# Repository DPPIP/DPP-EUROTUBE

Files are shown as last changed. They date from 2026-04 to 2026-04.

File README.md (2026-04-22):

# DPP Hyperloop – Eurotube / FHNW

## Übersicht

Das System erstellt **Digitale Produktpässe (DPP)** für Beton-Fertigelemente eines Hyperloop-Prototyps. Es besteht aus vier Schichten:

```
┌─────────────────────────────────────────────────────────┐
│  Arduino (Sensoren + RFID + Servo)                      │
│  ↕ Seriell (USB, 9600 Baud, JSON)                       │
│  Python GUI (Tkinter) – Produktionssteuerung             │
│  ↕ Git Push / GitHub Pages                               │
│  Web-Viewer (viewer.html, batch/index.html)              │
│  ↕ ifcopenshell                                          │
│  IFC-Integration (Pset-Schreiber)                        │
└─────────────────────────────────────────────────────────┘
```

---

## Verzeichnisstruktur

```
DPP-EUROTUBE/
├── index.html                              ← Landing Page (GitHub Pages)
├── README.md
├── prototyp_final/
│   ├── hyperloop_dpp.py                    ← Haupt-Python-Skript (GUI + Logik)
│   ├── hyperloop_qr_prep.py               ← QR-Label-Generator (PDF)
│   ├── hyperloop_dpp_combined/
│   │   └── hyperloop_dpp_combined.ino     ← Arduino-Sketch (Final)
│   └── qr_labels/
│       ├── labels.pdf                      ← Druckbare QR-Etiketten (A4)
│       └── prepared.json                   ← Manifest der generierten SNs
├── hardware/
│   ├── 3d_print/                           ← STL-Dateien (Schalung + Tisch)
│   │   ├── EuroTube_Mold_Left.stl / _V2.stl
│   │   ├── EuroTube_Mold_Right.stl / _V2.stl
│   │   ├── EuroTube_Table.stl / _V2.stl
│   │   └── EuroTube_Tubesegment.stl
│   └── arduino/
│       ├── sketch.ino                      ← Arduino-Sketch (Wokwi)
│       ├── diagram.json                    ← Elektronisches Schema (Wokwi)
│       ├── libraries.txt                   ← Bibliotheksliste
│       ├── wokwi-project.txt               ← Wokwi-Projekt-Link
│       └── komponenten.md                  ← Komponentenliste
├── passports/
│   ├── viewer.html                         ← Einzel-DPP Viewer (Web)
│   └── *.jsonld                            ← Generierte Segment-Passports
├── batch/
│   ├── index.html                          ← Batch-Viewer + Scanner (Web)
│   └── *.jsonld                            ← Generierte Batch-Passports
├── IFC/
│   ├── IP3.ifc                             ← Quell-IFC-Modell
│   ├── add_dpp_links.py                    ← V1: DPP-URLs ins IFC
│   ├── add_dpp_data.py                     ← V2: Alle DPP-Daten ins IFC
│   ├── IP3_DPP_Batchlinks.ifc             ← Output V1
│   └── IP3_DPP_abgefüllt.ifc             ← Output V2
├── Handlungsempfehlungen/
│   ├── handlungsempfehlungen.html          ← Viewer (GitHub Pages)
│   └── Handlungsempfehlungen_DPP.pdf      ← PDF
└── .gitignore
```

---

## 1. Hardware

### Komponenten

| Kategorie | Komponente |
|---|---|
| Mikrocontroller | Arduino Uno |
| Module und Sensoren | RFID-Modul RC522 |
| | DHT22 / DHT11 |
| Eingabe und Ausgabe | 2 Servomotoren |
| | Drucktaster |
| Verkabelung und Prototyping | Steckbrett, Widerstand, Jumperkabel |
| Stromversorgung | Batteriepack (4 × 1.5 V) |

### Elektronisches Schema

Das Schaltschema ist als Wokwi-Simulation verfügbar:  
`hardware/arduino/diagram.json` – importierbar unter https://wokwi.com/projects/461746891808954369

### 3D-Druckteile

Die physische Schalung (SMF) wurde als Prototyp gedruckt. Die STL-Dateien liegen unter `hardware/3d_print/`:

| Datei | Beschreibung |
|---|---|
| `EuroTube_Mold_Left.stl` / `_V2.stl` | Linke Schalungshälfte |
| `EuroTube_Mold_Right.stl` / `_V2.stl` | Rechte Schalungshälfte |
| `EuroTube_Table.stl` / `_V2.stl` | Produktionstisch |
| `EuroTube_Tubesegment.stl` | Röhrensegment-Modell |

---

## 2. Arduino – `hyperloop_dpp_combined.ino`

### Zweck
Steuert die physische Hardware: DHT11-Sensor (Temperatur/Feuchtigkeit), Servo (Schalung öffnen/schliessen), MFRC522 (RFID/NFC-Leser).

### Pin-Belegung

| Komponente | Pin |
|---|---|
| DHT11 | 2 |
| Taster | 3 (INPUT_PULLUP) |
| Servo | 6 |
| RFID RST | 9 |
| RFID SS | 10 |
| SPI | 11, 12, 13 (Standard) |

### Serielles Protokoll (JSON, 9600 Baud)

**Eingabe (Python → Arduino):**
- `C` – Schalung schliessen, Messung starten
- `O` – Schalung öffnen, Messung stoppen

**Ausgabe (Arduino → Python):**
```json
{"type":"boot","msg":"System bereit (DHT+Servo+RFID)"}
{"type":"event","event":"cmd_start"}
{"type":"sensor","grund":"periodic","temp":22.5,"hum":58.0,"servo":5}
{"type":"event","event":"cmd_stopp"}
{"type":"rfid","url":"https://w3id.org/hyperloop-dpp/01/09999000000001/21/1234567890"}
{"type":"rfid_error","msg":"Auth fehlgeschlagen"}
```

### RFID-Lesevorgang
- Liest NDEF-URL-Records von MIFARE Classic 1K Karten
- Sektor 1 (Blöcke 4–6) + Sektor 2 (Blöcke 8–10) = 96 Bytes
- Authentifizierung mit NFC-Forum-Key: `D3 F7 D3 F7 D3 F7`
- NDEF-Prefix `0x04` = `https://`, Terminator `0xFE` = Ende
- Nach erfolgreichem Scan wird `rfidAktiv = false` gesetzt (einmaliger Scan pro Zyklus)

### Ablauf
1. Taster oder `C`-Befehl → Schalung schliesst, Sensoraufzeichnung startet
2. Alle 2 Sekunden wird `{"type":"sensor",...}` gesendet
3. Taster oder `O`-Befehl → Schalung öffnet, RFID-Scan wird aktiviert
4. RFID-Karte erkannt → URL wird gesendet, Scan deaktiviert

---

## 3. Python GUI – `hyperloop_dpp.py`

### Zweck
Desktop-Anwendung (Tkinter) zur Produktionssteuerung. Empfängt Sensordaten vom Arduino, erstellt JSON-LD Passports und pusht sie via Git auf GitHub Pages.

### Abhängigkeiten
```
pip install pyserial qrcode[pil]
```
Optional (für Kamera-QR-Scan): `pip install opencv-python pyzbar`

### Konfiguration (Konstanten im Skript)

| Konstante | Wert | Beschreibung |
|---|---|---|
| `PORT` | `COM7` | Serieller Port des Arduino |
| `BAUD` | `9600` | Baudrate |
| `W3ID_BASE` | `https://w3id.org/hyperloop-dpp` | Basis-URI für GS1 Digital Links |
| `GTIN` | `09999000000001` | GS1 GTIN-14 des Produkts |
| `GITHUB_PAGES` | `https://DPPIP.github.io/DPP-EUROTUBE` | GitHub Pages URL |
| `GITHUB_REPO` | `C:/Users/david/Documents/DPP-EUROTUBE` | Lokaler Pfad zum Git-Repo |
| `BSDD_BASE` | `.../HYPER-DPP/0.6` | bSDD Datenkatalog Version |
| `BETONSORTE` | `C25/30` | Standardwert (überschreibbar in GUI) |
| `HERSTELLUNGSORT` | `Koblenz` | Standardwert (überschreibbar in GUI) |

### Hauptfunktionen

#### `extrahiere_id(scanned: str) -> str`
Extrahiert die Seriennummer aus einem GS1 Digital Link URI:
- `https://w3id.org/.../21/1234567890` → `1234567890`
- `https://w3id.org/.../10/4521` → `4521`
- `1234567890` → `1234567890`

#### `erstelle_jsonld(eintrag: dict) -> dict`
Generiert das JSON-LD Dokument für ein Segment. Verwendet bSDD 0.6 Property-Namen:

| JSON-LD Key | Inhalt |
|---|---|
| `bsdd:SegmentID` | Seriennummer |
| `bsdd:StrengthClass` | Betonsorte (aus GUI-Eingabe) |
| `bsdd:AssemblyPlace` | Herstellungsort (aus GUI-Eingabe) |
| `bsdd:ManufactoringDate` | ISO-Zeitstempel |
| `bsdd:ReferenceEnvironmentTemperature` | Durchschnittstemperatur in °C |
| `bsdd:ReferenceAirRelativeHumidity` | Durchschnittliche Luftfeuchtigkeit in % |
| `bsdd:Schalungsdauer` | Dauer in Stunden (Minuten / 60) |
| `bsdd:Status` | `Aktiv` |

#### `github_push(serial_nr: str, dateien: list)`
1. `git pull --rebase --autostash` (verhindert Konflikte)
2. Dateien ins Repo kopieren
3. `git add`, `git commit`, `git push`

#### `speichere_und_publiziere(t_med, h_med, dauer, segment_id)`
Erstellt JSON-LD, speichert lokal unter `passports/{sn}.jsonld`, pusht via Git.

#### `zeige_scan_dialog(t_med, h_med, dauer)`
Nach Produktionsstopp öffnet sich ein Dialog mit:
- **Kamera-Preview** (OpenCV + pyzbar) – erkennt QR-Codes automatisch
- **RFID-Callback** – Arduino sendet URL, Dialog reagiert automatisch
- **Manuelles Eingabefeld** – Fallback für USB-Scanner
- **Duplikatprüfung** – HEAD-Request auf GitHub Pages, verhindert doppelte Vergabe

#### `lese_seriell()`
Polling-Funktion (alle 100 ms via `root.after`). Verarbeitet JSON-Nachrichten vom Arduino:
- `cmd_start`/`system_start` → Aufzeichnung starten, Sensor-Arrays leeren
- `sensor` → Temperatur/Feuchtigkeit sammeln
- `rfid` → ID extrahieren, an Scan-Dialog weiterleiten
- `cmd_stopp`/`system_stopp` → Median berechnen, Scan-Dialog öffnen

### GUI-Elemente
- **Statusanzeige**: Schalung offen/geschlossen, aktueller Zustand
- **Eingabefelder**: Betonsorte und Herstellungsort (editierbar, Standardwerte)
- **Buttons**: "Schliessen & Start" / "Öffnen & Stopp"
- **DPP-Liste**: Scrollbare Liste aller erstellten Passports (Doppelklick öffnet im Browser)
- **URI-Label**: Klickbar, öffnet den zuletzt erstellten DPP im Browser

---

## 4. QR-Label-Generator – `hyperloop_qr_prep.py`

### Zweck
Generiert druckbare QR-Code-Etiketten als A4-PDF. Jedes Label enthält eine eindeutige GS1 Digital Link URI.

### Abhängigkeiten
```
pip install qrcode[pil] reportlab
```

### Konfiguration

| Konstante | Wert |
|---|---|
| `COUNT` | 11 (eindeutige SNs) |
| `COLS × ROWS` | 3 × 8 = 24 Plätze |
| Labels total | 13 (11 einmalig + 2 Duplikate) |

### Output
- `qr_labels/labels.pdf` – A4, randlos, QR 90° gedreht
- `qr_labels/prepared.json` – Manifest `[{id, uri, used}, ...]`

### Label-Aufbau
```
┌──────────────────────────────────┐
│ [QR 90°]  Digital Product Passport│
│           https://w3id.org/.../   │
│           01/GTIN/21/             │
│           1234567890  (fett)      │
└──────────────────────────────────┘
```

### Seriennummern
10-stellig, zufällig generiert (`random.randint(1000000000, 9999999999)`). Die ersten zwei SNs werden doppelt gedruckt (für Duplikat-Tests).

---

## 5. Web-Viewer – `passports/viewer.html`

### Zweck
Rendert ein einzelnes Segment-DPP im Browser. Wird auf GitHub Pages gehostet, Daten werden per Fetch aus den `.jsonld`-Dateien geladen.

### URL-Parameter
- `?sn=1234567890` – Seriennummer des Segments (Pflicht)
- `?single=1` – Batch-Redirect unterdrücken

### Ablauf
1. `sn` aus URL lesen
2. Fetch `passports/{sn}.jsonld` von GitHub Pages
3. Wenn `@type` = `HyperloopBatch` → Redirect zu `batch/index.html`
4. Wenn `bsdd:BatchID` vorhanden und kein `?single=1` → Redirect zum Batch
5. Render: 7 Felder (Betonsorte, Herstellungsort, Datum, Temperatur, Schalungsdauer, Status, Luftfeuchtigkeit)
6. QR-Code generieren (qrcodejs)

### Angezeigte Felder
| Feld | JSON-LD Key |
|---|---|
| Betonsorte | `bsdd:StrengthClass` |
| Herstellungsort | `bsdd:AssemblyPlace` |
| Herstellungsdatum | `bsdd:ManufactoringDate.@value` |
| Herstellungstemperatur | `bsdd:ReferenceEnvironmentTemperature.@value` |
| Dauer in der Schalung | `bsdd:Schalungsdauer.@value` |
| Status | `bsdd:Status` |
| Luftfeuchtigkeit | `bsdd:ReferenceAirRelativeHumidity.@value` |

---

## 6. Batch-Viewer – `batch/index.html`

### Zweck
Zwei Modi in einer Datei:
1. **Scanner-Modus** (`index.html` ohne Parameter): QR-Scanner zum Erstellen neuer Batches
2. **Batch-Ansicht** (`?batch=ID`): Anzeige eines bestehenden Batches

### Scanner-Modus
- Kamera-basierter QR-Scanner (html5-qrcode)
- 5 Segmente scannen → "Batch erstellen"
- Erstellt `batch/{batchId}.jsonld` via GitHub API (Token im localStorage)
- Schreibt `bsdd:BatchID` in jedes Segment-JSONLD zurück
- Duplikatschutz: Segment mit existierender BatchID wird abgelehnt

### Batch-Ansicht
- Titel: "Batch Röhrensegment 10 M"
- Batch-Karte: Batch-ID, Verbindungsdatum
- Bestandteile: Pro Segment → Bauteiltyp, Betonsorte, Herstellungsort, Temperatur, Schalungsdauer
- Status-Karte: Verbunden/offen, Einbaudatum
- Buttons: Link kopieren, JSON-LD anzeigen

### Batch JSON-LD Struktur
```json
{
  "@type": ["dpp:DigitalProductPassport", ".../HyperloopBatch"],
  "bsdd:Batch_ID": "4873316459",
  "bsdd:Verbindungsdatum": {"@value": "2026-04-15T10:35:24"},
  "bsdd:VerlinkungBauteile": ["https://w3id.org/.../21/SN1", "..."],
  "bsdd:Status": "Verbunden",
  "bsdd:Material": "SikaProof",
  "bsdd:Spannstahlsorte": "St1570",
  "bsdd:Klebertyp": "PCI"
}
```

---

## 7. IFC-Integration – `add_dpp_links.py` / `add_dpp_data.py`

### Zweck
Schreibt DPP-Informationen in ein bestehendes IFC-Modell (IP3.ifc) via ifcopenshell.

### Abhängigkeiten
```
pip install ifcopenshell
```

### IFC-Struktur

```
IfcElementAssembly  "Batch"       (Röhrensegment 10m = 5 Betonelemente)
  ├── IfcBuildingElementProxy  "Betonsegment_2m10"
  ├── IfcBuildingElementProxy  "Betonsegment_2m11"
  ├── IfcBuildingElementProxy  "Betonsegment_2m12"
  ├── IfcBuildingElementProxy  "Betonsegment_2m13"
  ├── IfcBuildingElementProxy  "Betonsegment_2m14"
  ├── IfcCovering              "Beschichtung"
  ├── IfcReinforcingBar        "Spannstahl" (×5)
  └── IfcFastener              "Kleber" (×4)
```

### Variante 1 – `add_dpp_links.py` → `IP3_DPP_v1.ifc`
Schreibt nur DPP-URLs in ein einziges Pset:

| Element | Pset | Property | Wert |
|---|---|---|---|
| IfcElementAssembly | `ePset_DigitalProductPassport` | `URL` | Batch-Viewer-Link |
| IfcBuildingElementProxy | `ePset_DigitalProductPassport` | `URL` | GS1 Digital Link URI |

### Variante 2 – `add_dpp_data.py` → `IP3_DPP_v2.ifc`
Schreibt alle DPP-Daten gemäss IFC-Mapping in mehrere Psets:

**IfcElementAssembly (Batch):**

| Pset | Properties |
|---|---|
| `ePset_DigitalProductPassport` | URL, Batch_ID, Verbindungsdatum, Status, Einbaudatum |

**IfcBuildingElementProxy (Segment):**

| Pset | Properties |
|---|---|
| `ePset_DigitalProductPassport` | URL |
| `Pset_ConcreteElementGeneral` | StrengthClass |
| `Pset_ManufacturerTypeInformation` | AssemblyPlace |
| `Pset_ManufacturerOccurrence` | ManufactoringDate |
| `Pset_EnvironmentalCondition` | ReferenceEnvironmentTemperature, ReferenceAtRelativeHumidity |
| `Pset_Herstellung` | Schalungsdauer, Status |

---

## URI-Schema (GS1 Digital Link)

```
https://w3id.org/hyperloop-dpp/01/{GTIN}/21/{Serial}   → Segment
https://w3id.org/hyperloop-dpp/01/{GTIN}/10/{BatchID}   → Batch
```

- **AI 01** = GTIN-14 (`09999000000001`)
- **AI 21** = Seriennummer (SGTIN, Segment-Ebene)
- **AI 10** = Losnummer (LGTIN, Batch-Ebene)
- W3ID leitet via `.htaccess` auf GitHub Pages weiter (PR pending bei perma-id/w3id.org)

---

## Datenfluss

```
1. Schalung schliessen (Button/Taster)
   → Arduino: Servo schliesst, Sensormessung startet

2. Sensordaten sammeln (alle 2s)
   → Arduino sendet JSON → Python sammelt Temperatur + Feuchtigkeit

3. Schalung öffnen (Button/Taster)
   → Arduino: Servo öffnet, RFID-Scan aktiviert
   → Python: Median berechnen, Scan-Dialog öffnen

4. QR-Code / RFID scannen
   → Kamera, RFID oder manuell → Segment-ID extrahiert
   → Duplikatprüfung (HEAD-Request auf GitHub Pages)

5. DPP erstellen und publizieren
   → JSON-LD generieren → lokal speichern
   → git pull --rebase → git add → git commit → git push
   → GitHub Pages aktualisiert automatisch

6. Batch erstellen (batch/index.html)
   → 5 Segmente scannen → Batch-JSONLD via GitHub API erstellen
   → BatchID in jedes Segment-JSONLD zurückschreiben

7. IFC-Integration (optional)
   → add_dpp_links.py oder add_dpp_data.py
   → Schreibt URLs / Daten in IFC-Psets
```

---

## Bekannte Limitierungen

- **Fehlerbehandlung**: `except Exception: pass` in der seriellen Leseroutine schluckt Fehler still. Bei Produktionseinsatz sollte Logging ergänzt werden.
- **Blockierender HTTP-Call**: Die Duplikatprüfung (`urllib.request.urlopen`) blockiert kurzzeitig die GUI. Bei schlechtem Netzwerk kann dies zu Verzögerungen führen.
- **Git-Push**: Verwendet `subprocess` für Git-Befehle. Bei Merge-Konflikten kann der Push fehlschlagen (wird in Konsole ausgegeben).
- **Kamera-Freigabe**: Bei unerwartetem Schliessen des Scan-Dialogs kann die Kamera-Ressource blockiert bleiben.
- **Prototyp-Charakter**: Das Skript ist für den Laborbetrieb an der FHNW konzipiert, nicht für industriellen Einsatz.

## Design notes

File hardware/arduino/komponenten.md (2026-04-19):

# Arduino Komponenten – Hyperloop DPP Prototyp

| Kategorie | Komponente |
|---|---|
| Mikrocontroller | Arduino Uno |
| Module und Sensoren | RFID-Modul RC522 |
| | DHT22 / DHT11 |
| Eingabe und Ausgabe | 2 Servomotoren |
| | Drucktaster |
| Verkabelung und Prototyping | Steckbrett |
| | Kleines Steckbrett |
| | Widerstand |
| | Jumperkabel |
| Stromversorgung | Batteriepack (4 × 1.5 V) |

## Simulation

Das Schaltschema wurde mit [Wokwi](https://wokwi.com/projects/461746891808954369) erstellt und simuliert.  
Die Dateien `sketch.ino` und `diagram.json` in diesem Ordner können direkt in Wokwi importiert werden.

## Pin-Belegung

| Komponente | Pin |
|---|---|
| DHT11/22 | 2 |
| Drucktaster | 3 (INPUT_PULLUP) |
| Servo | 6 |
| RFID RST | 9 |
| RFID SS (SDA) | 10 |
| RFID MOSI | 11 |
| RFID MISO | 12 |
| RFID SCK | 13 |

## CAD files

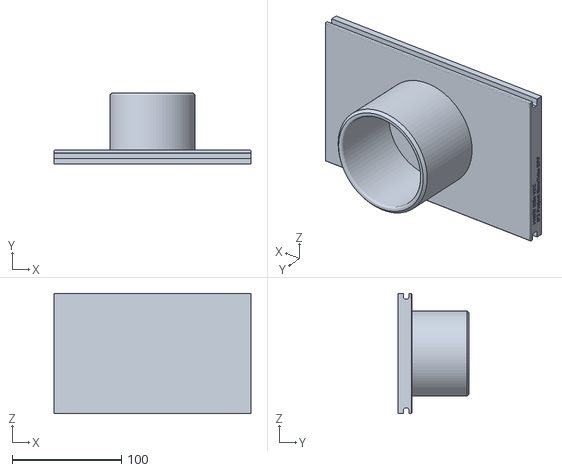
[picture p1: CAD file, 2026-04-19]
hardware/3d_print/EuroTube__Table_V2.stl
180.0 x 65.0 x 110.0

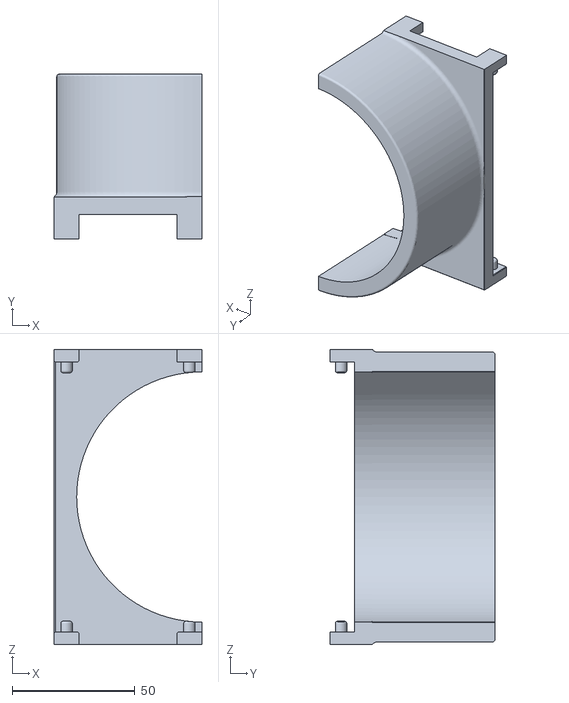
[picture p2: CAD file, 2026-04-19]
hardware/3d_print/EuroTube_Mold_Left.stl
60.0 x 67.0 x 120.0

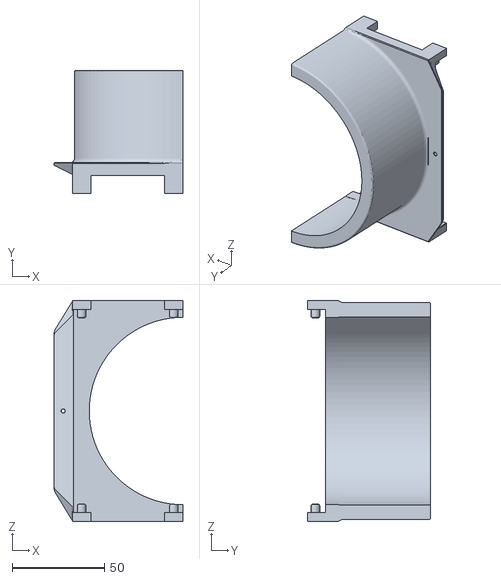
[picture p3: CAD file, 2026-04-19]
hardware/3d_print/EuroTube_Mold_Left_V2.stl
70.0 x 67.0 x 120.0

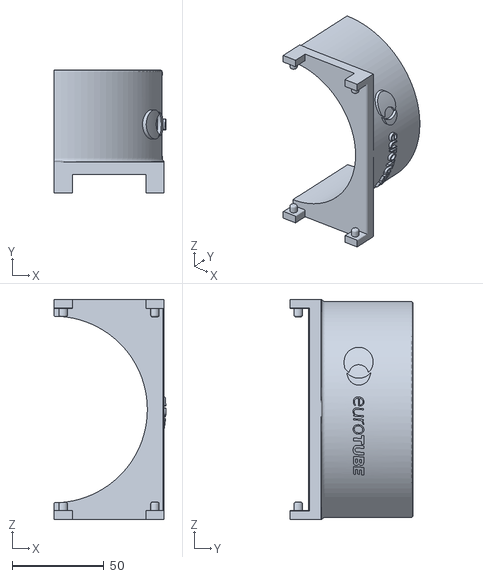
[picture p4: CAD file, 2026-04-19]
hardware/3d_print/EuroTube_Mold_Right.stl
61.0 x 67.0 x 120.0

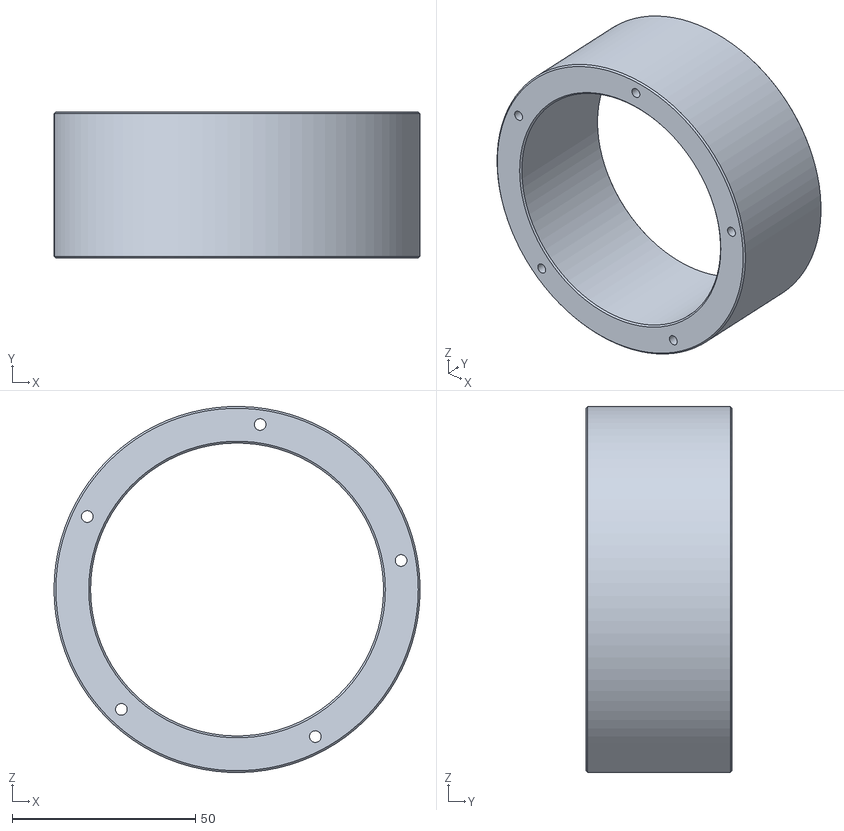
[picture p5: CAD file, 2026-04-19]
hardware/3d_print/EuroTube_Tubesegment.stl
100.0 x 40.0 x 100.0

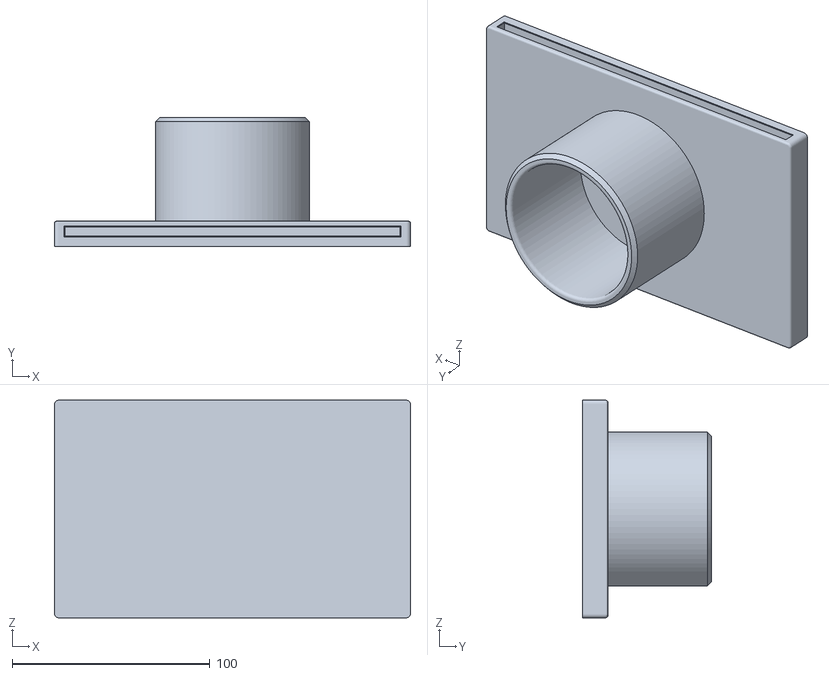
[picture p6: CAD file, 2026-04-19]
hardware/3d_print/EuroTube_Table.stl
180.0 x 65.0 x 110.0

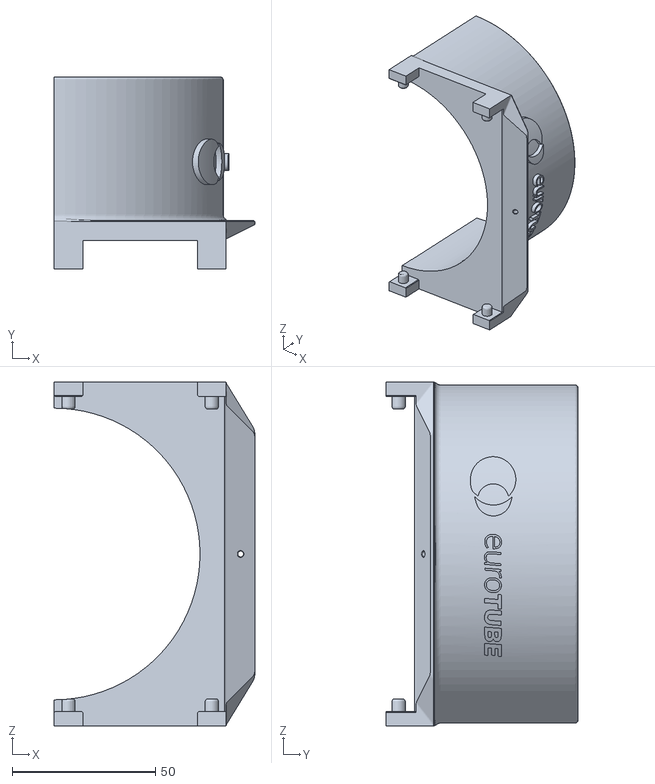
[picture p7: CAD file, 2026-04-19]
hardware/3d_print/EuroTube__Mold_Right_V2.stl
70.0 x 67.0 x 120.0

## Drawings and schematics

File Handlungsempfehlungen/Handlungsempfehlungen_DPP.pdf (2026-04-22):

## Digital Twin verbessern

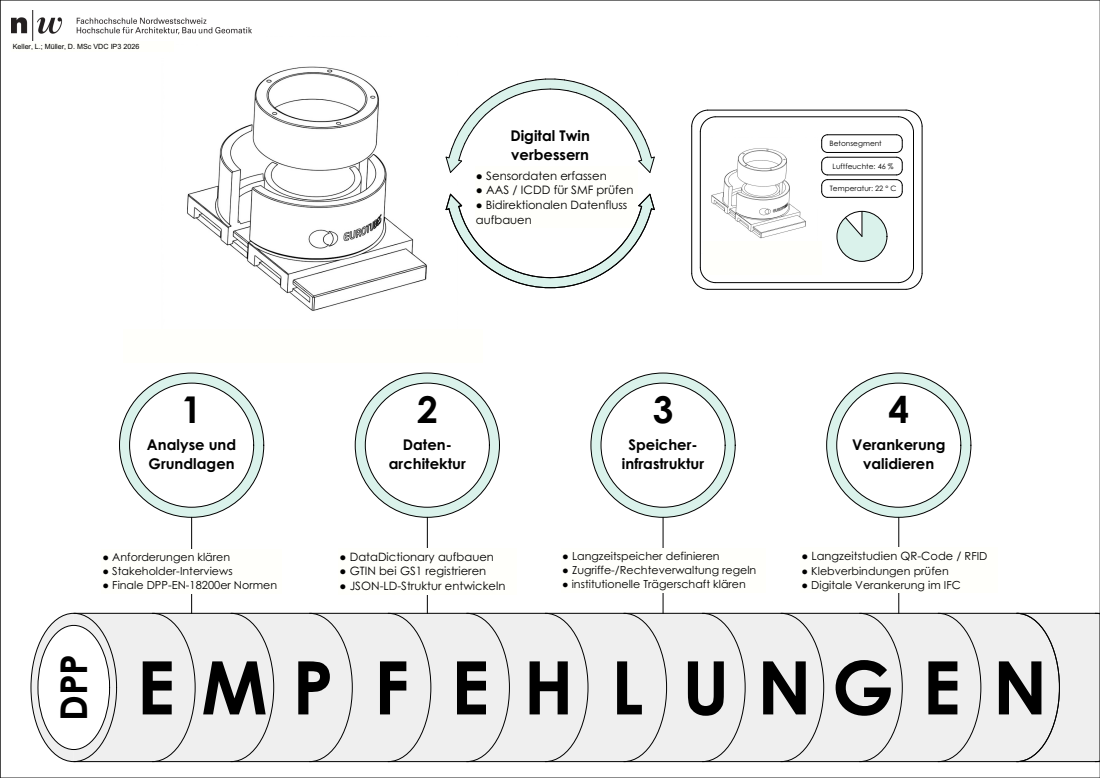
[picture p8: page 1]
GSEducationalVersion; Analyse und Grundlagen; Daten- architektur; Speicher- infrastruktur; Verankerung validieren; DPP; Betonsegment; Luftfeuchte: 46 %; Temperatur: 22 ° C

Keller, L.; Müller, D. MSc VDC IP3 2026

● Sensordaten erfassen
● AAS / ICDD für SMF prüfen
● Bidirektionalen Datenfluss
aufbauen

● Anforderungen klären
● Stakeholder-Interviews
● Finale DPP-EN-18200er Normen

● DataDictionary aufbauen
● GTIN bei GS1 registrieren
● JSON-LD-Struktur entwickeln

● Langzeitspeicher definieren
● Zugriffe-/Rechteverwaltung regeln
● institutionelle Trägerschaft klären

● Langzeitstudien QR-Code / RFID
● Klebverbindungen prüfen
● Digitale Verankerung im IFC

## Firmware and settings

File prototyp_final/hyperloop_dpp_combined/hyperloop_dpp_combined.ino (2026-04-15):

/**
 * hyperloop_dpp_combined.ino
 * ──────────────────────────
 * Kombiniert: DHT11-Sensor + Servo (Schalung) + RFID-Leser (MFRC522)
 *
 * Pins:
 *   DHT11   → Pin 2
 *   Taster  → Pin 3
 *   Servo   → Pin 6
 *   RFID RST→ Pin 9
 *   RFID SS → Pin 10
 *   RFID SPI→ 11 (MOSI), 12 (MISO), 13 (SCK) [Standard Arduino SPI]
 *
 * Bibliotheken:
 *   DHT sensor library (Adafruit)
 *   Servo (built-in)
 *   MFRC522 (Miguel Balboa)
 *
 * Protokoll (seriell, 9600 Baud):
 *   Befehle von Python: 'C' = schliessen/start, 'O' = öffnen/stopp
 *   Ausgaben JSON:
 *     {"type":"boot","msg":"System bereit"}
 *     {"type":"event","event":"cmd_start"}
 *     {"type":"sensor","grund":"periodic","temp":22.5,"hum":58.0,"servo":5}
 *     {"type":"event","event":"cmd_stopp"}
 *     {"type":"rfid","url":"https://w3id.org/hyperloop-dpp/SN-..."}
 *     {"type":"rfid_error","msg":"Karte nicht lesbar"}
 */

#include "DHT.h"
#include <Servo.h>
#include <SPI.h>
#include <MFRC522.h>

// ─── Pins ────────────────────────────────────────────────────────────────────
#define DHTPIN       2
#define DHTTYPE      DHT11
#define TASTER_PIN   3
#define SERVO_PIN    6
#define RST_PIN      9
#define SS_PIN       10

// ─── Intervalle ──────────────────────────────────────────────────────────────
#define SENSOR_INTERVALL 2000

// ─── Objekte ─────────────────────────────────────────────────────────────────
DHT      dht(DHTPIN, DHTTYPE);
Servo    schalung;
MFRC522  mfrc522(SS_PIN, RST_PIN);
MFRC522::MIFARE_Key rfidKey;

// ─── Zustandsvariablen ───────────────────────────────────────────────────────
bool sensorAktiv          = false;
bool rfidAktiv            = false;   // true = Scan wird erwartet (Schalung offen)
bool letzterTasterZustand = HIGH;
unsigned long letzterSensorSend = 0;
int aktuellerWinkel       = 85;


// ─── Hilfsfunktionen ─────────────────────────────────────────────────────────

void sendeStatus(const char* grund) {
  float temp = dht.readTemperature();
  float hum  = dht.readHumidity();

  Serial.print("{\"type\":\"sensor\",\"grund\":\"");
  Serial.print(grund);
  Serial.print("\",\"temp\":");
  if (!isnan(temp)) Serial.print(temp, 1); else Serial.print("\"null\"");
  Serial.print(",\"hum\":");
  if (!isnan(hum))  Serial.print(hum, 1);  else Serial.print("\"null\"");
  Serial.print(",\"servo\":");
  Serial.print(aktuellerWinkel);
  Serial.println("}");
}

void oeffneSchalung() {
  schalung.attach(SERVO_PIN);
  aktuellerWinkel = 85;
  schalung.write(aktuellerWinkel);
  delay(400);
  schalung.detach();
}

void schliesseSchalung() {
  schalung.attach(SERVO_PIN);
  aktuellerWinkel = 5;
  schalung.write(aktuellerWinkel);
  delay(400);
  schalung.detach();
}

// ─── RFID lesen ──────────────────────────────────────────────────────────────

void leseRFID() {
  if (!mfrc522.PICC_IsNewCardPresent() || !mfrc522.PICC_ReadCardSerial()) return;

  MFRC522::StatusCode status;
  byte buffer[18];
  byte size = sizeof(buffer);
  String fullData = "";

  // Authentifizierung Sektor 1 (Block 4) und lese Blöcke 4–6
  status = mfrc522.PCD_Authenticate(
    MFRC522::PICC_CMD_MF_AUTH_KEY_A, 4, &rfidKey, &(mfrc522.uid)
  );
  if (status != MFRC522::STATUS_OK) {
    Serial.println("{\"type\":\"rfid_error\",\"msg\":\"Auth fehlgeschlagen\"}");
    mfrc522.PICC_HaltA();
    return;
  }
  for (byte block = 4; block <= 6; block++) {
    status = mfrc522.MIFARE_Read(block, buffer, &size);
    if (status == MFRC522::STATUS_OK) {
      for (byte i = 0; i < 16; i++) fullData += (char)buffer[i];
    }
  }

  // Authentifizierung Sektor 2 (Block 8) und lese Blöcke 8–10
  status = mfrc522.PCD_Authenticate(
    MFRC522::PICC_CMD_MF_AUTH_KEY_A, 8, &rfidKey, &(mfrc522.uid)
  );
  if (status == MFRC522::STATUS_OK) {
    for (byte block = 8; block <= 10; block++) {
      status = mfrc522.MIFARE_Read(block, buffer, &size);
      if (status == MFRC522::STATUS_OK) {
        for (byte i = 0; i < 16; i++) fullData += (char)buffer[i];
      }
    }
  }

  mfrc522.PICC_HaltA();
  mfrc522.PCD_StopCrypto1();

  // URL aus NDEF-Daten extrahieren
  String url = "";
  int headerIndex = -1;

  for (int i = 0; i < (int)fullData.length(); i++) {
    if (fullData[i] == 0x55) { headerIndex = i; break; }
  }

  if (headerIndex != -1 && headerIndex + 1 < (int)fullData.length()) {
    byte prefix = fullData[headerIndex + 1];
    if      (prefix == 0x01) url = "http://www.";
    else if (prefix == 0x02) url = "https://www.";
    else if (prefix == 0x03) url = "http://";
    else if (prefix == 0x04) url = "https://";

    for (int i = headerIndex + 2; i < (int)fullData.length(); i++) {
      byte c = fullData[i];
      if (c == 0xFE) break;
      if (c >= 32 && c <= 126) url += (char)c;
    }
  }

  if (url.length() > 0) {
    Serial.print("{\"type\":\"rfid\",\"url\":\"");
    Serial.print(url);
    Serial.println("\"}");
    rfidAktiv = false;  // Einmalig – nach erfolgtem Scan zurücksetzen
  } else {
    Serial.println("{\"type\":\"rfid_error\",\"msg\":\"Keine URL auf Karte\"}");
  }
}


// ─── Setup ───────────────────────────────────────────────────────────────────

void setup() {
  Serial.begin(9600);
  dht.begin();
  pinMode(TASTER_PIN, INPUT_PULLUP);

  // Servo Startposition
  schalung.attach(SERVO_PIN);
  schalung.write(aktuellerWinkel);
  delay(400);
  schalung.detach();

  // SPI + RFID initialisieren
  SPI.begin();
  mfrc522.PCD_Init();

  // NFC-Forum Key (D3 F7 D3 F7 D3 F7)
  for (byte i = 0; i < 6; i++) {
    rfidKey.keyByte[i] = (i % 2 == 0) ? 0xD3 : 0xF7;
  }

  Serial.println("{\"type\":\"boot\",\"msg\":\"System bereit (DHT+Servo+RFID)\"}");
}


// ─── Loop ────────────────────────────────────────────────────────────────────

void loop() {

  // ── 1. Befehle von Python lesen ──────────────────────────────────────────
  if (Serial.available() > 0) {
    char cmd = Serial.read();

    if (cmd == 'C') {
      sensorAktiv = true;
      rfidAktiv   = false;   // kein Scan während Messung
      schliesseSchalung();
      Serial.println("{\"type\":\"event\",\"event\":\"cmd_start\"}");
      sendeStatus("start");
      letzterSensorSend = millis();
    }
    else if (cmd == 'O') {
      sensorAktiv = false;
      rfidAktiv   = true;    // Scan wird jetzt erwartet
      oeffneSchalung();
      Serial.println("{\"type\":\"event\",\"event\":\"cmd_stopp\"}");
    }
  }

  // ── 2. Taster abfragen ───────────────────────────────────────────────────
  bool aktuellerTasterZustand = digitalRead(TASTER_PIN);

  if (aktuellerTasterZustand == LOW && letzterTasterZustand == HIGH) {
    sensorAktiv = !sensorAktiv;
    schalung.attach(SERVO_PIN);

    if (sensorAktiv) {
      rfidAktiv = false;
      schliesseSchalung();
      Serial.println("{\"type\":\"event\",\"event\":\"system_start\"}");
      sendeStatus("start");
      letzterSensorSend = millis();
    } else {
      rfidAktiv = true;      // Scan erwartet nach manuellem Öffnen
      oeffneSchalung();
      Serial.println("{\"type\":\"event\",\"event\":\"system_stopp\"}");
    }
    delay(50);
  }

  letzterTasterZustand = aktuellerTasterZustand;

  // ── 3. Sensordaten senden ────────────────────────────────────────────────
  if (sensorAktiv) {
    unsigned long jetzt = millis();
    if (jetzt - letzterSensorSend >= SENSOR_INTERVALL) {
      letzterSensorSend = jetzt;
      sendeStatus("periodic");
    }
  }

  // ── 4. RFID prüfen (nur wenn Scan erwartet wird) ─────────────────────────
  if (rfidAktiv) {
    leseRFID();
  }
}

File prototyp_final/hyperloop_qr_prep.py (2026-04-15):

"""
hyperloop_qr_prep.py – QR-Code Vorbereitung
============================================
Erstellt vorgedruckte QR-Code Labels mit W3ID URIs.

Output:
  qr_labels/labels.pdf   – druckbares A4-PDF, 3 Spalten × 8 Zeilen, QR 90° gedreht
  qr_labels/prepared.json – Manifest der generierten SNs

Verwendung:
    python hyperloop_qr_prep.py

Abhängigkeiten:
    pip install qrcode[pil] reportlab
"""

import os
import io
import json
import random
import base64
from io import BytesIO

# ─── CONFIG ──────────────────────────────────────────────────────────────────

W3ID_BASE  = "https://w3id.org/hyperloop-dpp"
GTIN       = "09999000000001"   # GS1 GTIN-14
COUNT      = 11                 # 11 unterschiedliche SNs
OUTPUT_DIR = "qr_labels"

COLS = 3
ROWS = 8

# ─────────────────────────────────────────────────────────────────────────────


def generate_serial() -> str:
    return str(random.randint(1000000000, 9999999999))


def make_qr_image(uri: str):
    """Gibt ein PIL-Image des QR-Codes zurück."""
    try:
        import qrcode
        qr = qrcode.QRCode(
            version=None,
            error_correction=qrcode.constants.ERROR_CORRECT_M,
            box_size=8,
            border=2
        )
        qr.add_data(uri)
        qr.make(fit=True)
        return qr.make_image(fill_color="black", back_color="white").convert("RGB")
    except ImportError:
        print("[!] qrcode nicht installiert: pip install qrcode[pil]")
        return None


def make_pdf(labels: list, path: str):
    try:
        from reportlab.pdfgen import canvas
        from reportlab.lib.pagesizes import A4
        from reportlab.lib.units import mm
        from reportlab.lib.utils import ImageReader
        from PIL import Image
    except ImportError:
        print("[!] reportlab nicht installiert: pip install reportlab")
        return

    W, H = A4  # 595.27 × 841.89 pt

    # Randlos: Etiketten füllen die gesamte A4-Seite
    cell_w = W / COLS
    cell_h = H / ROWS

    c = canvas.Canvas(path, pagesize=A4)

    for i, label in enumerate(labels[:COLS * ROWS]):
        col = i % COLS
        row = i // COLS

        x0 = col * cell_w
        y0 = H - (row + 1) * cell_h

        pad = 1.5 * mm

        # QR-Code: 90° gedreht, etwas kleiner als Zellhöhe
        qr_size = cell_h * 0.78

        if label.get("img"):
            img_rotated = label["img"].rotate(90, expand=True)
            buf = BytesIO()
            img_rotated.save(buf, format="PNG")
            buf.seek(0)
            ir = ImageReader(buf)
            # QR vertikal zentriert, kleiner Abstand vom linken Rand
            qr_y = y0 + (cell_h - qr_size) / 2
            c.drawImage(ir, x0 + 2 * mm, qr_y, qr_size, qr_size, mask="auto")

        # Text rechts vom QR
        text_x = x0 + 2 * mm + qr_size + 2.5 * mm
        center_y = y0 + cell_h / 2

        # URI aufteilen
        uri = label["uri"]
        if "/01/" in uri and "/21/" in uri:
            base   = uri.split("/01/")[0] + "/"
            middle = "01/" + uri.split("/01/")[1].split("/21/")[0] + "/21/"
            serial = uri.split("/21/")[1]
        else:
            base, middle, serial = uri, "", label["id"]

        # "Digital Product Passport"
        c.setFont("Helvetica", 5.5)
        c.setFillColorRGB(0.45, 0.45, 0.45)
        c.drawString(text_x, center_y + 8, "Digital Product Passport")

        # URI Zeile 1 + 2 (klein, grau)
        c.setFont("Helvetica", 4.5)
        c.setFillColorRGB(0.65, 0.65, 0.65)
        c.drawString(text_x, center_y + 1,  base)
        c.drawString(text_x, center_y - 4, middle)

        # Seriennummer (letzte Zahlen) – fett, gut lesbar
        c.setFont("Helvetica-Bold", 8)
        c.setFillColorRGB(0.1, 0.1, 0.1)
        c.drawString(text_x, center_y - 13, serial)

    c.save()
    print(f"  PDF gespeichert: {path}")


def main():
    os.makedirs(OUTPUT_DIR, exist_ok=True)

    # 11 unterschiedliche SNs generieren
    unique = []
    for _ in range(COUNT):
        serial = generate_serial()
        uri = f"{W3ID_BASE}/01/{GTIN}/21/{serial}"
        print(f"  Generiere {serial} -> {uri}")
        img = make_qr_image(uri)
        unique.append({"id": serial, "uri": uri, "img": img})

    # 2 davon doppelt -> total 13 Etiketten
    labels = unique + [unique[0], unique[1]]
    print(f"\n  Duplikate: {unique[0]['id']} (2x), {unique[1]['id']} (2x)")

    # PDF
    pdf_path = os.path.join(OUTPUT_DIR, "labels.pdf")
    make_pdf(labels, pdf_path)

    # Manifest (nur die 11 eindeutigen SNs)
    manifest_path = os.path.join(OUTPUT_DIR, "prepared.json")
    with open(manifest_path, "w", encoding="utf-8") as f:
        json.dump([{"id": l["id"], "uri": l["uri"], "used": False}
                   for l in unique], f, indent=2)

    print(f"  13 Labels (11 einmalig + 2x2) -> {pdf_path}")
    print(f"  Manifest  -> {manifest_path}")


if __name__ == "__main__":
    main()

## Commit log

2026-03-19 Fix Windows encoding errors and add new DPP entries
    Replace non-ASCII Unicode symbols (checkmark, arrow) in print statements
    with ASCII equivalents to prevent cp1252 codec crashes on Windows.
    Adds 3 new DPP passport entries recorded during the session.
    [hyperloop_dpp.py]
2026-03-19 DPP-Link öffnet lokale HTML-Datei sofort im Browser
    Klick auf URI-Label öffnet die lokale Passport-Datei direkt,
    ohne auf GitHub Pages warten zu müssen.
2026-03-19 HTML unter GS1-Pfad speichern damit W3ID-URI direkt funktioniert
    Passport wird als 01/GTIN/10/BATCH/21/SN/index.html gespeichert,
    sodass die GS1 Digital Link URI direkt auf GitHub Pages aufrufbar ist.
    QR-Code, GUI-Link und Listbox zeigen alle auf die korrekte URI.
2026-03-20 Archiv und Passports zurueckgesetzt
2026-03-24 Fix JSON-LD Link: direkt auf GitHub Pages statt W3ID
    [hyperloop_dpp.py]
2026-03-24 QR-Code Fallback auf GitHub Pages bis W3ID-Fix gemergt
    [hyperloop_dpp.py]
2026-04-06 Normen und Granularitaet entfernt
2026-04-08 Batch-Redirect: QR-Code öffnet direkt Batch-Ansicht mit Aggregation
    - Passport HTML redirected automatisch zu batch/index.html?batch=LOT-xxx
    - ?single=1 Parameter für direkte Einzel-Ansicht
    - manifest.json für Batch-Zugehörigkeit aller Passports
    - batch/index.html: Aggregation-Baum (◇ LOT → Segmente)
    - Fix: JSON-LD Parsing von espr: auf bsdd: Eigenschaften
    - hyperloop_dpp.py: aktualisiere_manifest() Funktion
    [hyperloop_dpp.py]
2026-04-08 6 neue Test-DPPs: LOT-2026-15 (SN-1775650015 bis SN-1775650040)
    Alle alten Passports gelöscht und neu generiert mit:
    - Batch-Redirect (QR → Batch-Ansicht)
    - manifest.json aktualisiert
    - bsdd: JSON-LD Format
2026-04-08 Scanner schreibt Verbindungsdatum via GitHub API in batch/LOT-xxx.jsonld
    - GitHub API Integration (PAT aus localStorage)
    - createBatch() erfasst ISO-Timestamp als Verbindungsdatum
    - Erstellt batch/LOT-xxx.jsonld mit BatchStatus=Verbunden und VerlinkungBauteile
    - showBatchViewById() lädt batch .jsonld für persistiertes Verbindungsdatum
    - Token-Modal (einmalige Eingabe, localStorage)
    - MAX_ITEMS: 5 → 6
2026-04-09 Batch LOT-2026-15 verbunden – 2026-04-09T07:37:22
2026-04-11 fix: dynamic batch redirect via manifest lookup
    - Passport HTMLs no longer hardcode batch ID at creation time
    - On page load: fetch manifest.json → check if SN has a batch → HEAD
    check → redirect only if batch .jsonld exists
    - V2: batch = "" at creation, assigned only when operator creates batch
    - batch/index.html: updateManifest() writes batch ID to manifest.json
    for each segment after batch creation
    - SN_REGEX updated to support alphanumeric serials
2026-04-11 chore: clear all V1 test data, reset manifest
    Remove all old passports (SN-177..., SEG-001, SN-ZR1LVIV1, SN-XCE8B9WP)
    and batch files (LOT-2026-15.jsonld). Fresh start for V2 prototype test.
2026-04-11 revert: use numeric SN serials to match existing w3id.org .htaccess
    Alphanumeric IDs would require a new w3id PR. Numeric 10-digit random
    serials match existing SN-[0-9]+ rule already merged in perma-id/w3id.org.
    [hyperloop_qr_prep.py]
2026-04-11 feat: block duplicate QR scans in batch scanner
    Two-level duplicate check:
    1. Already in current session -> toast warning
    2. Already assigned to a previous batch (manifest check) -> blocked
    with error toast + double vibration
2026-04-12 feat: RFID support in V2 + combined Arduino sketch
    Arduino (hyperloop_dpp_combined.ino):
    - Merges DHT+Servo with MFRC522 RFID reader
    - rfidAktiv flag: RFID only scanned when schalung is open
    - Outputs {"type":"rfid","url":"..."} when card detected
    - Outputs {"type":"rfid_error","msg":"..."} on failure
    Python (hyperloop_dpp_v2.py):
    - Global _scan_callback set when scan dialog opens
    - lese_seriell() handles rfid messages → calls callback
    - Callback cleared on dialog close/skip/destroy
    - Status label shows "QR-Code oder RFID-Karte"
    [hyperloop_dpp_combined.ino]
2026-04-12 Batch LOT-UNBEKANNT verbunden – 2026-04-12T07:56:49
2026-04-12 fix: generate BatchID locally via ISO week (LOT-YYYY-WW)
    - Replace fetch-from-segment approach (caused LOT-UNBEKANNT fallback)
    - genBatchId() computes LOT-2026-15 style ID from current date
    - Remove LOT-UNBEKANNT.jsonld
2026-04-12 Batch LOT-2026-15 verbunden – 2026-04-12T08:14:51
2026-04-12 batch/index.html: Batch-Label-Scan-Schritt entfernt
    Kein physisches Batch-Label mehr nötig. Batch-SN wird automatisch
    als zufällige 10-stellige Zahl generiert. Scanner startet direkt.
2026-04-12 Archiv geleert: alte HTML-Passports und Batch-JSONLD entfernt
2026-04-12 Projekt in prototyp1/ und prototyp2/ aufgeteilt
    prototyp1/: hyperloop_dpp.py (erster Prototyp)
    prototyp2/: hyperloop_dpp_v2.py, hyperloop_dpp_combined.ino,
    hyperloop_qr_prep.py, qr_labels/
2026-04-15 DPP Datenmodell auf bSDD 0.6 aktualisiert
    Segment: StrengthClass, AssemblyPlace, ManufactoringDate,
    ReferenceEnvironmentTemperature, ReferenceAirRelativeHumidity,
    Schalungsdauer (h), Status
    Batch: Batch_ID, Status, Material, Spannstahlsorte, Klebertyp
2026-04-15 Arduino: Sektor 2 (Blöcke 8-10) lesen für lange URLs
    URL war abgeschnitten vor /21/ (nur 48 Bytes aus Sektor 1).
    Jetzt 96 Bytes -> volle GS1 Digital Link URL lesbar.
2026-04-15 Batch 4873316459 verbunden – 2026-04-15T10:35:24
2026-04-15 IFC: DPP-Links und Daten via ifcopenshell eingebettet (v1 + v2)
2026-04-15 Landing Page erstellt, README entfernt
2026-04-19 Hardware: 3D-Druckfiles, Arduino Wokwi-Schema und Komponentenliste hinzugefuegt
    [EuroTube_Mold_Left.stl, EuroTube_Mold_Left_V2.stl, EuroTube_Mold_Right.stl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]
2026-04-22 Handlungsempfehlungen: PDF.js + Vollbild-Button (Fullscreen API)
2026-04-22 Handlungsempfehlungen: Download-Button hinzugefügt
2026-04-22 Handlungsempfehlungen: Download-Button über Vollbild-Button
2026-04-22 Handlungsempfehlungen: Renderqualität mit devicePixelRatio verbessert
2026-04-22 Handlungsempfehlungen: Buttons gleich gross
2026-04-22 Handlungsempfehlungen: einheitliche Schrift, GitHub-Button
2026-04-22 Handlungsempfehlungen: Schriftart Century Gothic für Buttons
2026-04-22 Handlungsempfehlungen: Icons von Buttons entfernt
2026-04-22 Batch 8984735876 verbunden – 2026-04-22T11:53:10
2026-04-22 Batch 5502407674 verbunden – 2026-04-22T12:39:36
2026-04-22 Batch-Scanner: Eingabefeld und Bild-Upload entfernt
2026-04-22 Batch-Scanner: stufenweiser Kamera-Fallback (1080p → facingMode → any)
2026-04-22 Batch 9318572030 verbunden – 2026-04-22T13:40:58
2026-04-22 Passports: bereinigt – nur Batch 4873316459 behalten
2026-04-22 Batch: 9318572030 entfernt – nur Batch 4873316459 behalten
2026-04-22 Handlungsempfehlungen: QR-Code Button mit Label-Overlay
2026-04-22 Handlungsempfehlungen: QR-Button CSS-Selektor korrigiert
2026-04-23 Batch 7608753004 verbunden – 2026-04-23T12:59:37
